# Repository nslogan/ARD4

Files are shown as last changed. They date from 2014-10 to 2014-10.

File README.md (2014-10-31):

# ARD4

## Description

Optically-isolated 4-channel automotive relay driver (ARD). Intended for use in lab environment, robust and flexible driver with 1A output possible per channel. Jumper to select between active-high and active-low inputs, jumper to select between DB9 or external power for input side. Reverse-protection on both logic and relay side power. LED across relay driver output indicates if **relay** is getting power. Test points for logic and relay power, as well as one per channel on logic side. Board fits Sick of Beige DP8049 form factor (but should be used with 10mm stand-offs between board and top panel). You can find [this project on GitHub](https://github.com/nslogan/ARD4).

## Production

The board measures 3.15"x1.93" (80.01x49.02 mm) and was designed for production at [OSH Park](https://www.oshpark.com/). The OSHPark DRU is located in the `res/` folder.

The boards can be purchased [here](https://www.oshpark.com/shared_projects/R0TELkwq) @ $30.35 for three.

## Parts

All parts on this board are from the [LoganSmith-Eagle-Library](https://github.com/nslogan/LoganSmith-Eagle-Library) available on GitHub (work in progress).

The BOM is located in the release folder, all parts are sourced from Digi-Key.

## Project Structure

This project adheres to this structure:

	[ProjectName]
		README.md
		[release]
			[Major.Minor]
				ProjectName_BOM_Major.Minor.xls or ProjectName_BOM_BOM_Major.Minor.csv
				ProjectName_schematic_Major.Minor.pdf
				ProjectName_board-<top/mid#/bottom>_Major.Minor.png
				ProjectName_Major.Minor.sch
				ProjectName_Major.Minor.brd
				[Gerbers]
					...
			...
		[src]
			[Major.0]
				BoardName.sch
				BoardName.brd
				BOM.xls or BOM.csv
			[Major+1.0]
				...
			...
		[lib]
			...
		[res]
			Manufacturer.dru
			Manufacturer.cam

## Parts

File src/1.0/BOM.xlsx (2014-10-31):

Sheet: Sheet1
Qty | Parts | Package | Description | Digikey OC | Height | Manufacturer | MPN | TEMP
4 | C1, C2, C3, C4 | 0805-CAP
1 | J4 | DB9-R90 | D-Sub female, right-angle, 9 pos, gold | A35107-ND |  | TE Connectivity | 1734354-1
8 | R2, R4, R5, R6, R9, R10, R13, R14 | 0805-RES | RES 10K OHM 1/8W 5% 0805 SMD | P10KACT-ND |  | Panasonic Electronic Components | ERJ-6GEYJ103V
4 | R1, R7, R11, R15 | 0805-RES | 1k 0805 resistor 0.125W 5% | P1.0KACT-ND |  | Panasonic Electronic Components | ERJ-6GEYJ102V
4 | U1, U2, U3, U4 | SOD-123 | Constant Current Regulator, 45Vmax, 20mA +/-15%, SOD-123 | NSI45020T1GOSCT-ND |  | ON Semiconductor | NSI45020T1G | -40C to 85C
4 | R3, R8, R12, R16 | 0805-RES | 330 0805 resistor 0.125W 5% | P330ACT-ND |  | Panasonic Electronic Components | ERJ-6GEYJ331V
8 | Q1, Q2, Q7, Q8, Q11, Q12, Q15, Q16 | SOT23-3 | NPN 40V 200mA SOT-23-3 350mW | MMBT3904-FDICT-ND |  | Diodes Incorporated | MMBT3904-7-F | -55C to 150C
1 | D1 | SOD-323 | Schottky 40V 0.35A SOD323, 600mV Vf | SD103AWS-FDICT-ND |  | Diodes Incorporated | SD103AWS-7-F | -65C to 125C
4 | D3, D7, D10, D13 | SOD-123 | Zener 5.1V 500mW SOD123, 900mV Vf | MMSZ5231B-FDICT-ND |  | Diodes Incorporated | MMSZ5231B-7-F | -65C to 150C
4 | Q4, Q6, Q10, Q14 | SOT23-3 | MOSFET N-Channel 60V 1.2A SOT23-3 1.25W | IRLML2060TRPBFCT-ND |  | International Rectifier | IRLML2060TRPBF | -55C to 150C
4 | D4, D8, D11, D14 | SMA-DIODE | Schottky 60V 2A SMA, 700mV Vf | B260A-FDICT-ND |  | Diodes Incorporated | B260A-13-F | -65C to 150C
1 | D2 | SMC-DIODE | Schottky 60V 5A SMC, 700mV Vf | B560C-FDICT-ND |  | Diodes Incorporated | B560C-13-F | -55C to 125C
4 | D5, D6, D9, D12 | 1206-LED | Clear Blue LED, 1206, 3.3V Vf, 20mA | 160-1643-1-ND | 1.1mm | Lite-On Inc. | LTST-C150KBKT | -30C to 85C
4 | Q3, Q5, Q9, Q13 | 4-SMD | Optoisolator 5kV, Transistor Output, 1.2V Vf, 50mA If | FOD817DSDCT-ND |  | Fairchild Semiconductor | FOD817DSD | -55C to 110C
6 | J1, J2, J3, J5, J9, J11 | SOCKET-3.5MM-2-R90 | Terminal block 2 pos R90 3.5mm black | WM7770-ND | 6.9mm | Molex Inc | 0395021002
6 | P1, P2, P3, P5, P9, P11 | PLUG-3.5MM-2 | Terminal block plug 2 pos straight 3.5mm black | WM7732-ND |  | Molex Inc | 0395000002
6 | J6, J7, J8, J10, J12, J13 | 1x02 | 0.1" header 1x2 gold 30uin black male 0.23" mating | 609-3500-ND | 8mm | FCI | 68000-102HLF
2 | TP1, TP2 | TP_THRU_CIRC | Test point PC mini 0.04"D red | 5000K-ND | 4.57mm | Keystone Electronics | 5000
2 | TP3, TP4 | TP_THRU_CIRC | Test point PC mini 0.04"D black | 5001K-ND | 4.57mm | Keystone Electronics | 5001
4 | TP5, TP6, TP7, TP8 | TP_THRU_CIRC | Test point PC mini 0.04"D white | 5002K-ND | 4.57mm | Keystone Electronics | 5002
5 | JP1, JP2, JP3, JP4, JP5 | 1x02 | Shunt jumper 0.1" black gold | 3M9580-ND | 6mm | 3M | 969102-0000-DA

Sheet: Sheet2
Qty | Value | Device | Package | Parts | DESC | DIGIKEY_OC | HEIGHT | MFR | MPN | TEMP
4 | OPT | C-0805 | 0805-CAP | C1, C2, C3, C4
1 | DB9-R90-F | DB9-R90-F | DB9-R90 | J4 | D-Sub female, right-angle, 9 pos, gold | A35107-ND |  | TE Connectivity | 1734354-1
8 | 10k | 10K-5%-0805 | 0805-RES | R2, R4, R5, R6, R9, R10, R13, R14 | RES 10K OHM 1/8W 5% 0805 SMD | P10KACT-ND |  | Panasonic Electronic Components | ERJ-6GEYJ103V
4 | 1k | 1K-5%-0805 | 0805-RES | R1, R7, R11, R15 |  | P1.0KACT-ND |  | Panasonic Electronic Components | ERJ-6GEYJ102V
4 | 20mA | NSI45020T1G | SOD-123 | U1, U2, U3, U4 | Constant Current Regulator, 45Vmax, 20mA +/-15%, SOD-123 | NSI45020T1GOSCT-ND |  | ON Semiconductor | NSI45020T1G | -40C to 85C
4 | 330 | 330-5%-0805 | 0805-RES | R3, R8, R12, R16 |  | P330ACT-ND |  | Panasonic Electronic Components | ERJ-6GEYJ331V
8 | 40V,0.2A | MMBT3904 | SOT23-3 | Q1, Q2, Q7, Q8, Q11, Q12, Q15, Q16 | NPN 40V 200mA SOT-23-3 350mW | MMBT3904-FDICT-ND |  | Diodes Incorporated | MMBT3904-7-F | -55C to 150C
1 | 40V,0.35A | SD103AWS-7-F | SOD-323 | D1 | Schottky 40V 0.35A SOD323, 600mV Vf | SD103AWS-FDICT-ND |  | Diodes Incorporated | SD103AWS-7-F | -65C to 125C
4 | 5.1V | MMSZ5231B-7-F | SOD-123 | D3, D7, D10, D13 | Zener 5.1V 500mW SOD123, 900mV Vf | MMSZ5231B-FDICT-ND |  | Diodes Incorporated | MMSZ5231B-7-F | -65C to 150C
4 | 60V,1.2A | IRLML2060TRPBF | SOT23-3 | Q4, Q6, Q10, Q14 | MOSFET N-Channel 60V 1.2A SOT23-3 1.25W | IRLML2060TRPBFCT-ND |  | International Rectifier | IRLML2060TRPBF | -55C to 150C
4 | 60V,2A | B260A-13-F | SMA-DIODE | D4, D8, D11, D14 | Schottky 60V 2A SMA, 700mV Vf | B260A-FDICT-ND |  | Diodes Incorporated | B260A-13-F | -65C to 150C
1 | 60V,5A | B560C-13-F | SMC-DIODE | D | Schottky 60V 5A SMC, 700mV Vf | B560C-FDICT-ND |  | Diodes Incorporated | B560C-13-F | -55C to 125C
4 | BLUE | LTST-C150KBKT | 1206-LED | D5, D6, D9, D12 | Clear Blue LED, 1206, 3.3V Vf, 20mA | 160-1643-1-ND | 1.1mm | Lite-On Inc. | LTST-C150KBKT | -30C to 85C
4 | FOD817A | FOD817A | 4-SMD | Q3, Q5, Q9, Q13 | Optoisolator 5kV, Transistor Output, 1.2V Vf, 50mA If | FOD817DSDCT-ND |  | Fairchild Semiconductor | FOD817DSD | -55C to 110C
6 | 1x02-90 | M02SKT-3.5MM-R90 | SOCKET-3.5MM-2-R90 | J1, J2, J3, J5, J9, J11
6 | 1x02 | M02SQ1 | 1X02_SQ1 | J6, J7, J8, J10, J12, J13
6 | TP-THRU-B | TP-THRU-B | TP_THRU_CIRC | TP3, TP4, TP5, TP6, TP7, TP8
2 | TP-THRU-R | TP-THRU-R | TP_THRU_CIRC | TP1, TP2

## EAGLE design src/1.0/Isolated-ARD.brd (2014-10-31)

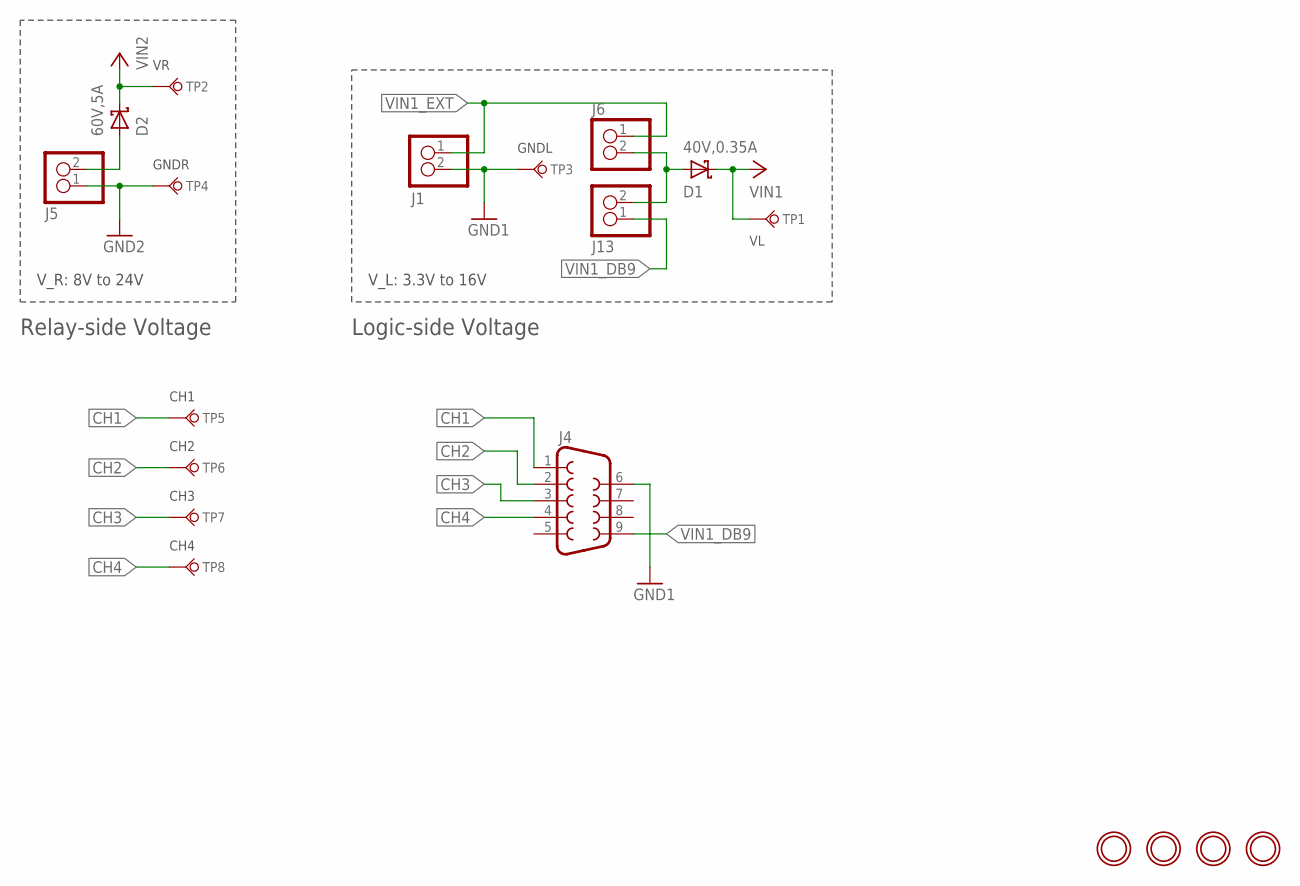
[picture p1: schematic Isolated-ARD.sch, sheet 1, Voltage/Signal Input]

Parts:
D1: 40V,0.35A; SOD-323
D2: 60V,5A; SMC-DIODE
J1, J5: M02SKT-3.5MM-R90; SOCKET-3.5MM-2-R90
J4: DB9-R90-F; DB9-R90
J6, J13: M02SQ1; 1X02_SQ1
TP1, TP2: TP-THRU-R; TP_THRU_CIRC
TP3, TP4, TP5, TP6, TP7, TP8: TP-THRU-B; TP_THRU_CIRC
U$13, U$14, U$15, U$21: MNTHOLE-M3; MNTHOLE_M3_PLATED

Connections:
CH1: J4.1, TP5.TP; also elsewhere on the board
CH2: J4.2, TP6.TP; also elsewhere on the board
CH3: J4.3, TP7.TP; also elsewhere on the board
CH4: J4.4, TP8.TP; also elsewhere on the board
GND1: J1.2, J4.6, TP3.TP; also elsewhere on the board
GND2: J5.1, TP4.TP; also elsewhere on the board
unnamed: D1.A, J6.2, J13.2
VIN1: D1.C, TP1.TP; also elsewhere on the board
VIN1_DB9: J4.9, J13.1
VIN1_EXT: J1.1, J6.1
VIN2: D2.C, TP2.TP; also elsewhere on the board
VIN2_EXT: D2.A, J5.2

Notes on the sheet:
V_L: 3.3V to 16V
V_R: 8V to 24V
Logic-side Voltage
Relay-side Voltage

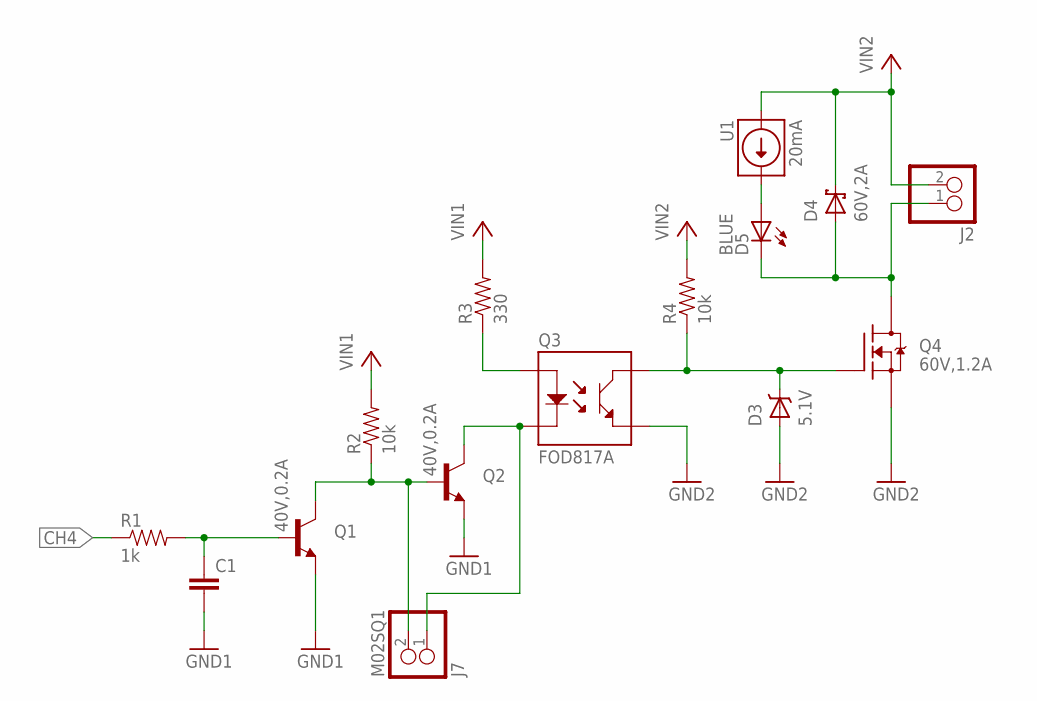
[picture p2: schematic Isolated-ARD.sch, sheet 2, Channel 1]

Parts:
C1: C-0805; 0805-CAP
D3: 5.1V; SOD-123
D4: 60V,2A; SMA-DIODE
D5: BLUE; 1206-LED; MPN LTST-C150KBKT; DIGIKEY_OC 160-1643-1-ND
J2: M02SKT-3.5MM-R90; SOCKET-3.5MM-2-R90
J7: M02SQ1; 1X02_SQ1
Q1, Q2: 40V,0.2A; SOT23-3
Q3: FOD817A; 4-SMD
Q4: 60V,1.2A; SOT23-3
R1: 1k; 0805-RES
R2: 10k; 0805-RES
R3: 330; 0805-RES
R4: 10k; 0805-RES; MPN ERJ-6GEYJ103V; DIGIKEY_OC P10KACT-ND
U1: 20mA; SOD-123

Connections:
CH4: R1.P$1 (1); also elsewhere on the board
GND1: C1.P$2 (2), Q1.2 (E), Q2.2 (E); also elsewhere on the board
GND2: D3.A, Q3.3 (T_E), Q4.2 (S); also elsewhere on the board
unnamed: J7.2, Q1.3 (C), Q2.1 (B), R2.P$1 (1)
unnamed: J7.1, Q2.3 (C), Q3.2 (LED_C)
unnamed: Q3.1 (LED_A), R3.P$1 (1)
unnamed: C1.P$1 (1), Q1.1 (B), R1.P$2 (2)
unnamed: D3.C, Q3.4 (T_C), Q4.1 (G), R4.P$1 (1)
unnamed: D4.A, D5.C, J2.1, Q4.3 (D)
unnamed: D5.A, U1.C
VIN1: R2.P$2 (2), R3.P$2 (2); also elsewhere on the board
VIN2: D4.C, J2.2, R4.P$2 (2), U1.A; also elsewhere on the board

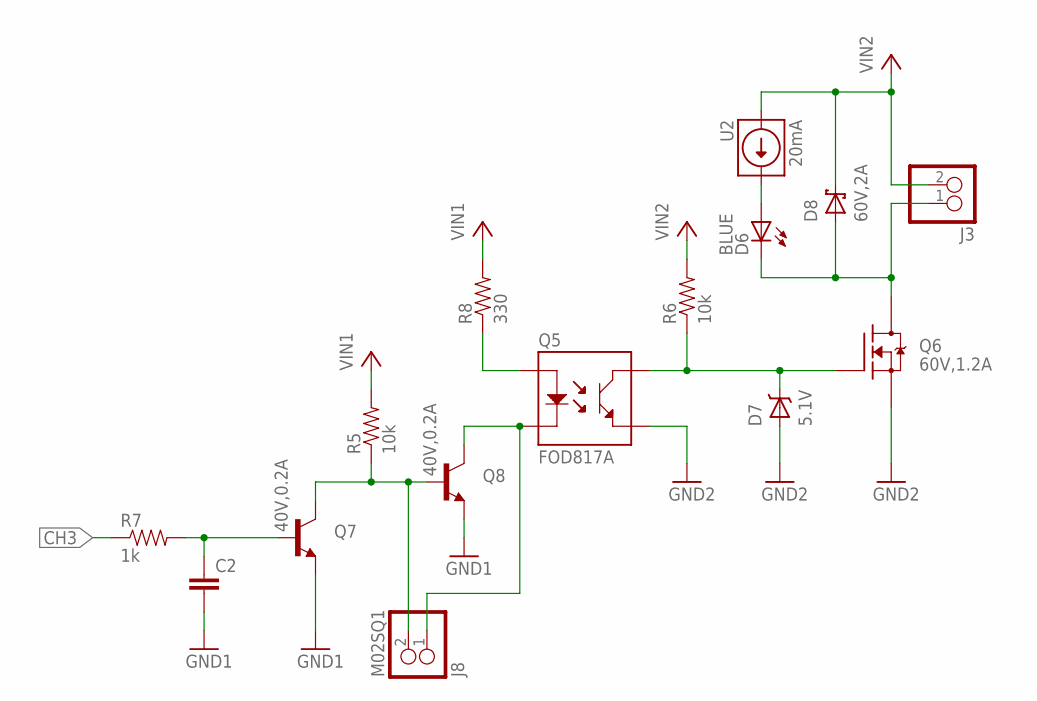
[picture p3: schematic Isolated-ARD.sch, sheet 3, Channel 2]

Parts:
C2: C-0805; 0805-CAP
D6: BLUE; 1206-LED; MPN LTST-C150KBKT; DIGIKEY_OC 160-1643-1-ND
D7: 5.1V; SOD-123
D8: 60V,2A; SMA-DIODE
J3: M02SKT-3.5MM-R90; SOCKET-3.5MM-2-R90
J8: M02SQ1; 1X02_SQ1
Q5: FOD817A; 4-SMD
Q6: 60V,1.2A; SOT23-3
Q7, Q8: 40V,0.2A; SOT23-3
R5: 10k; 0805-RES
R6: 10k; 0805-RES; MPN ERJ-6GEYJ103V; DIGIKEY_OC P10KACT-ND
R7: 1k; 0805-RES
R8: 330; 0805-RES
U2: 20mA; SOD-123

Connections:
CH3: R7.P$1 (1); also elsewhere on the board
GND1: C2.P$2 (2), Q7.2 (E), Q8.2 (E); also elsewhere on the board
GND2: D7.A, Q5.3 (T_E), Q6.2 (S); also elsewhere on the board
unnamed: J8.1, Q5.2 (LED_C), Q8.3 (C)
unnamed: Q5.1 (LED_A), R8.P$1 (1)
unnamed: D7.C, Q5.4 (T_C), Q6.1 (G), R6.P$1 (1)
unnamed: J8.2, Q7.3 (C), Q8.1 (B), R5.P$1 (1)
unnamed: C2.P$1 (1), Q7.1 (B), R7.P$2 (2)
unnamed: D6.C, D8.A, J3.1, Q6.3 (D)
unnamed: D6.A, U2.C
VIN1: R5.P$2 (2), R8.P$2 (2); also elsewhere on the board
VIN2: D8.C, J3.2, R6.P$2 (2), U2.A; also elsewhere on the board

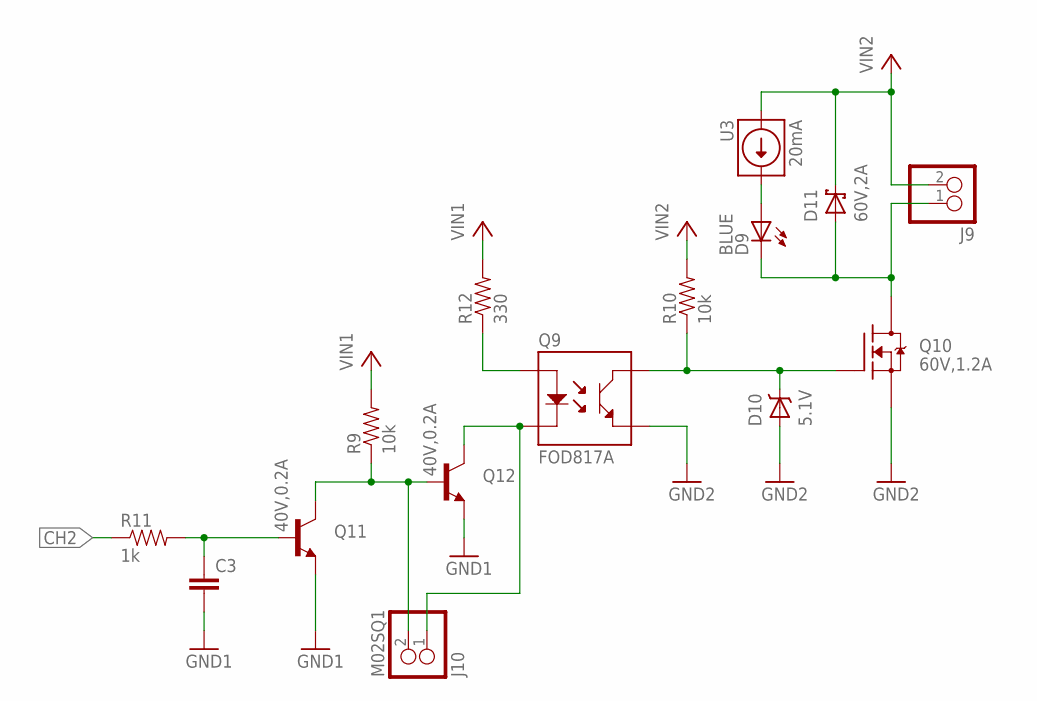
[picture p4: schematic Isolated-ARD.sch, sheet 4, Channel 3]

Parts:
C3: C-0805; 0805-CAP
D9: BLUE; 1206-LED; MPN LTST-C150KBKT; DIGIKEY_OC 160-1643-1-ND
D10: 5.1V; SOD-123
D11: 60V,2A; SMA-DIODE
J9: M02SKT-3.5MM-R90; SOCKET-3.5MM-2-R90
J10: M02SQ1; 1X02_SQ1
Q9: FOD817A; 4-SMD
Q10: 60V,1.2A; SOT23-3
Q11, Q12: 40V,0.2A; SOT23-3
R9: 10k; 0805-RES
R10: 10k; 0805-RES; MPN ERJ-6GEYJ103V; DIGIKEY_OC P10KACT-ND
R11: 1k; 0805-RES
R12: 330; 0805-RES
U3: 20mA; SOD-123

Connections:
CH2: R11.P$1 (1); also elsewhere on the board
GND1: C3.P$2 (2), Q11.2 (E), Q12.2 (E); also elsewhere on the board
GND2: D10.A, Q9.3 (T_E), Q10.2 (S); also elsewhere on the board
unnamed: J10.1, Q9.2 (LED_C), Q12.3 (C)
unnamed: Q9.1 (LED_A), R12.P$1 (1)
unnamed: D10.C, Q9.4 (T_C), Q10.1 (G), R10.P$1 (1)
unnamed: J10.2, Q11.3 (C), Q12.1 (B), R9.P$1 (1)
unnamed: C3.P$1 (1), Q11.1 (B), R11.P$2 (2)
unnamed: D9.C, D11.A, J9.1, Q10.3 (D)
unnamed: D9.A, U3.C
VIN1: R9.P$2 (2), R12.P$2 (2); also elsewhere on the board
VIN2: D11.C, J9.2, R10.P$2 (2), U3.A; also elsewhere on the board

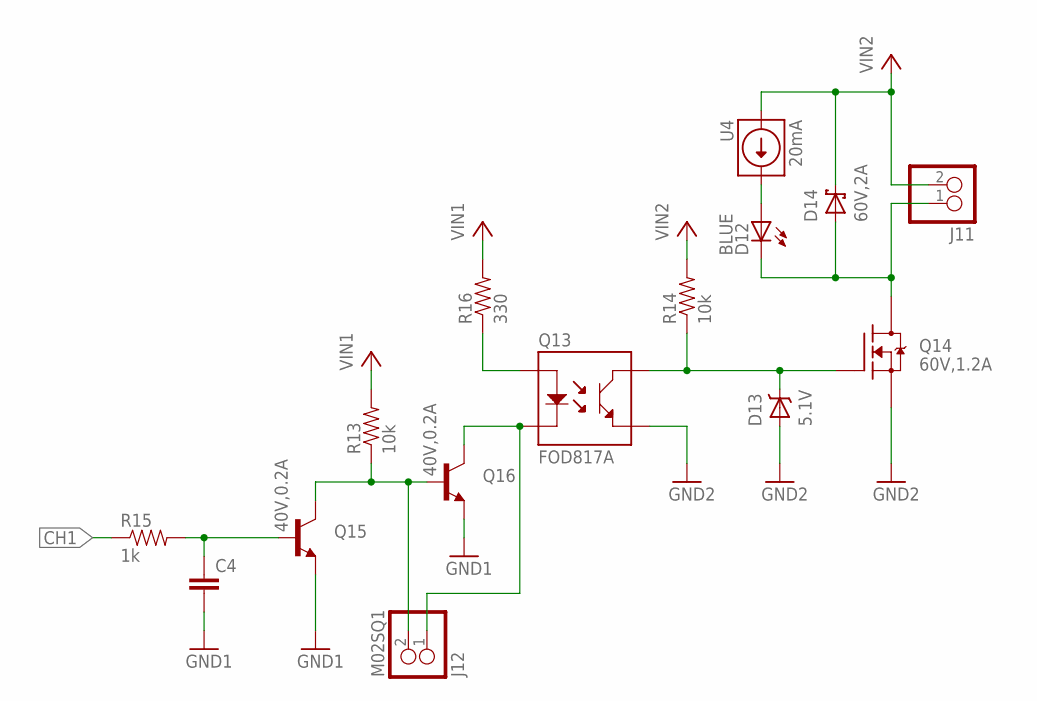
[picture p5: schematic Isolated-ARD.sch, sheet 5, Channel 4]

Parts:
C4: C-0805; 0805-CAP
D12: BLUE; 1206-LED; MPN LTST-C150KBKT; DIGIKEY_OC 160-1643-1-ND
D13: 5.1V; SOD-123
D14: 60V,2A; SMA-DIODE
J11: M02SKT-3.5MM-R90; SOCKET-3.5MM-2-R90
J12: M02SQ1; 1X02_SQ1
Q13: FOD817A; 4-SMD
Q14: 60V,1.2A; SOT23-3
Q15, Q16: 40V,0.2A; SOT23-3
R13: 10k; 0805-RES
R14: 10k; 0805-RES; MPN ERJ-6GEYJ103V; DIGIKEY_OC P10KACT-ND
R15: 1k; 0805-RES
R16: 330; 0805-RES
U4: 20mA; SOD-123

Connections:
CH1: R15.P$1 (1); also elsewhere on the board
GND1: C4.P$2 (2), Q15.2 (E), Q16.2 (E); also elsewhere on the board
GND2: D13.A, Q13.3 (T_E), Q14.2 (S); also elsewhere on the board
unnamed: J12.1, Q13.2 (LED_C), Q16.3 (C)
unnamed: Q13.1 (LED_A), R16.P$1 (1)
unnamed: D13.C, Q13.4 (T_C), Q14.1 (G), R14.P$1 (1)
unnamed: J12.2, Q15.3 (C), Q16.1 (B), R13.P$1 (1)
unnamed: C4.P$1 (1), Q15.1 (B), R15.P$2 (2)
unnamed: D12.C, D14.A, J11.1, Q14.3 (D)
unnamed: D12.A, U4.C
VIN1: R13.P$2 (2), R16.P$2 (2); also elsewhere on the board
VIN2: D14.C, J11.2, R14.P$2 (2), U4.A; also elsewhere on the board

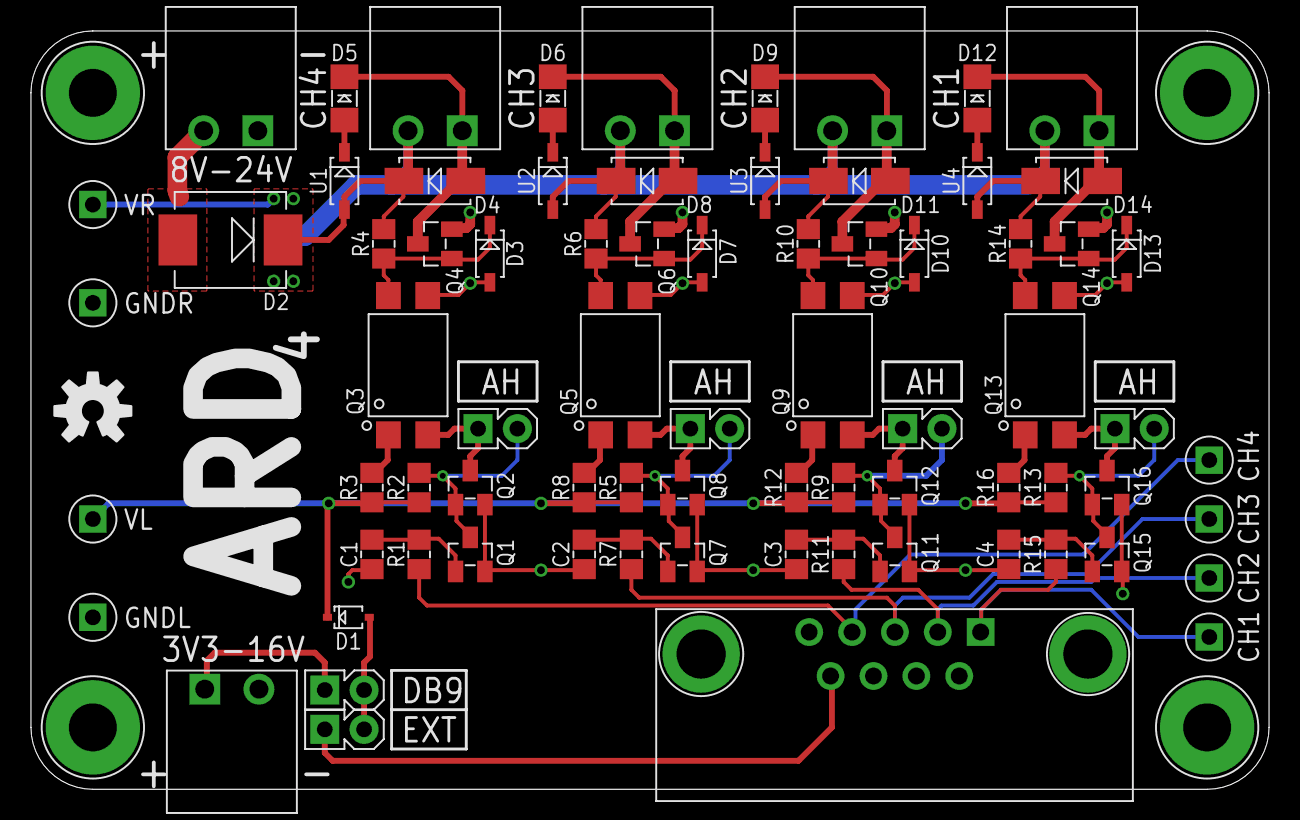
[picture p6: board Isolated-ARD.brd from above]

Board: 2 copper layers, 80.0 x 49.0 mm, 81 parts (0 on the bottom side), 40 nets.

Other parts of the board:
U$12: DP8049_V1_PLATED
U$16: OSHW-LOGO-M

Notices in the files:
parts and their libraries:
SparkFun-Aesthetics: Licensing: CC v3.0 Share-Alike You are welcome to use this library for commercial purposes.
